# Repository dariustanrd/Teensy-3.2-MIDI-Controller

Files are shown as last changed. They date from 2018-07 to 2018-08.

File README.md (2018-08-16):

# Teensy 3.2 MIDI Controller / Macropad
A custom MIDI Controller / Macropad based on the [Teensy 3.2 microcontroller](https://www.pjrc.com/store/teensy32.html) for [MIDI2LR](https://github.com/rsjaffe/MIDI2LR/) integration and multi-keystroke macro execution.

Images of the final product can be seen either in this [gallery](https://imgur.com/a/6ZGOYGf) or at the end of this README.

## Inspiration for this project

Firstly, I was facing issues with editing a large number of images in Adobe Lightroom as it often takes a long time and it was not very intuitive to edit with my laptop's touchpad. Therefore, I stumbled upon MIDI2LR which uses MIDI Controllers normally used for music production to act as a physical device to change values in Lightroom.

Secondly, I wanted to create a macropad to perform tasks that would normally require multiple keypresses on the keyboard, such as while coding, CAD-ing etc., with a single press of a key.

Therefore, this controller serves 2 main purposes:
1. To send USB MIDI CC / NOTE messages in order to interface with MIDI2LR.
  
2. To send USB keyboard presses in order to chain multiple keypresses into a single macro key.

## Build Process
1. Mechanical & Electrical Fabrication
   
    I first purchased [this aluminium enclosure](https://item.taobao.com/item.htm?id=542717489532&_u=t2dmg8j26111) from Taobao, an online Chinese retailer, and milled out the holes for the encoders and the key switches to pass through. I designed a grid for the key switches in SolidWorks and fabricated it with a water jet machine out of 2mm Aluminium (which should have been 1.5mm Alu in hindsight). I then sand blasted the aluminium components and spray painted them black for aesthetic purposes.

   In order to cater for multiple functions on a single board, I added a SPDT Toggle Switch to connect to 2 digital pins on the Teensy to act as a Layer control mechanism to increase or decrease the current layer.

   As the Teensy has limited I/O slots and I wanted a large number of mechanical keyboard switches on my device to cater to the size of the enclosure I purchased, I wired up the Gateron Brown keyboard switches as well as the Encoder pushbuttons in a 4 x 7 matrix, with the help of the [Cherry MX breakout board](https://learn.sparkfun.com/tutorials/cherry-mx-switch-breakout-hookup-guide), similar to that of a regular keyboard matrix.

   Lastly, I wired all the components up to my Teensy 3.2, including 8 Incremental Rotary Encoders ([PEC11R-4215K-S0024](http://sg.element14.com/webapp/wcs/stores/servlet/ProductDisplay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)), 1 Potentiometer, 1 WS2812B LED strip, 1 SPDT toggle switch, my 4 x 7 switch matrix and 1 lonely Encoder pushbutton that could not fit on my switch matrix.

2. Code
   
   The first challenge that I tackled was interfacing with the Incremental Rotary Encoders. I used the [Teensy Encoder.h library](https://www.pjrc.com/teensy/td_libs_Encoder.html) for its ease of use and its interrupt capabilities since all digital pins on the Teensy 3.2 are interrupt capable.

   For the MIDI portion of the project, as my main purpose of using MIDI messages was to interface with MIDI2LR, I decided to send MIDI CC messages when I rotated my rotary encoders and MIDI NOTE messages when I pressed my mechanical key switches or encoder pushbuttons.

   Thus, when I rotated the encoders, which are mapped to specific CC numbers, the CC value would increment or decrement correspondingly on the MIDI channel that is defined by the current Layer that the device is in (controlled by the toggle switch).

   For the 4 x 7 keyswitch matrix, I setup a state machine in order to properly set the states of each individual switch be it IDLE, PRESSED, HOLD or RELEASED. Then, if the layer is currently on the lightroom layer, whether the switch is pressed or held, different MIDI NOTE messages will be sent. Otherwise, a keyboard macro will be sent instead. To send the keyboard press, the inbuilt [Teensy keyboard libary](https://www.pjrc.com/teensy/td_keyboard.html) is used. However, as there is no USB type for "Serial + MIDI + Keyboard", I edited the "Serial + MIDI" USB type in usb_desc.h to include keyboard functionality as well (inspiration from [here](https://forum.pjrc.com/threads/23942-Using-Serial-and-MIDI-USB-types-at-the-same-time).)

   Lastly, to be able to physically ascertain what layer the device is currently in, I changed the colour of the WS2812B LED strip using the [Teensy WS2812Serial.h library](https://github.com/PaulStoffregen/WS2812Serial) and added a cycling rainbow pattern for fun in the highest layer (which actually causes the teensy to be unable to perform other tasks, hence that layer is technically unusable but its just there for the sake of it).

## Images
Completed Device:
Top Profile

Side Profile of Device:
Side Profile

Milled Aluminium Enclosure:
Milled Alu Enclosure

Pre-assembly Layout:
Pre-assembly Layout

Internal Wiring:
Internal Wiring

Internal Wiring Closeup:
Internal Wiring Closeup

Front Profile:
Front Profile

Top Profile:
Top Profile

## GIFs
Top Profile GIF:

Top Profile GIF

Side Profile GIF:

Side Profile GIF

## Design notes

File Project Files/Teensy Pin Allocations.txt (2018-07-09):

Teensy 3.2 Pin Allocations

THROUGH HOLE
0 - ENC1A
1 - ENC1B
2 - ENC2A
3 - ENC2B
4 - ENC3A
5 - ENC3B
6 - ENC4A
7 - ENC4B
8 - ENC5A
9 - ENC5B
10 - ENC6A
11 - ENC6B
12 - ENC1PB
13 - RES/LED2 (Int LED)
14 - ENC7B
15 - ENC7A
16 - ENC8B
17 - ENC8A
18 - MATROW1
19 - MATROW2
20 - MATROW3
21 - MATROW4
22/A8 - TRIMPOT1
23/A9 - LINPOT1 ?

REAR PADS
24 - MATCOL7
25 - MATCOL6
26 - MATCOL5
27 - MATCOL4
28 - MATCOL3
29 - MATCOL2
30/A19 - SW_DWN
31/A20 - LED1
32/PWM - SW_UP
33 - MATCOL1

add switch

MATRIX
		MATCOL1	MATCOL2	MATCOL3	MATCOL4	MATCOL5	MATCOL6	MATCOL7

MATROW4		30		31		32		33		34		35		36
MATROW3		20		21		22		23		24		25		26
MATROW2		10		11		12		13		14		15		16
MATROW1		00		01		02		03		04		05		06

MIDI CC
ENC1 - 0
ENC2 - 1
ENC3 - 2
ENC4 - 3
ENC5 - 4
ENC6 - 5
ENC7 - 6
ENC8 - 7

ENC1PB - 8
ENC2PB - 9
ENC3PB - 10
ENC4PB - 11
ENC5PB - 12
ENC6PB - 13
ENC7PB - 14
ENC8PB - 15

K1->K21 - 16->36

1 enc detent = 5 cc val
24 enc det = 120 cc val

if 
1 enc det = 4 cc
24 enc det = 96 cc

Functions
-Hold button to increase sensitivity of encoders
	- done by using 1 detent = less num
use NOTE for keypads
change midi channel for layer

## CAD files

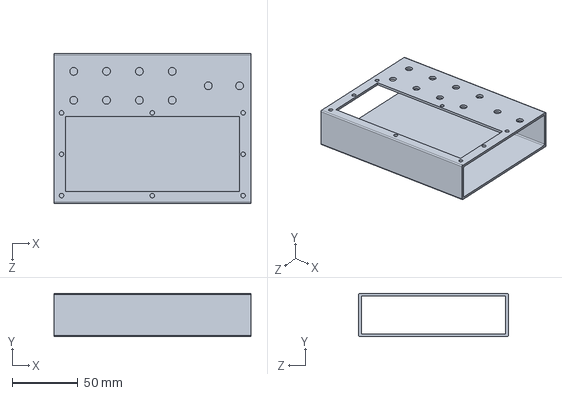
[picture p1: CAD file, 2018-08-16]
Project Files/CAD/Aluminium Enclosure.SLDPRT
150.0 x 33.1 x 114.0 mm

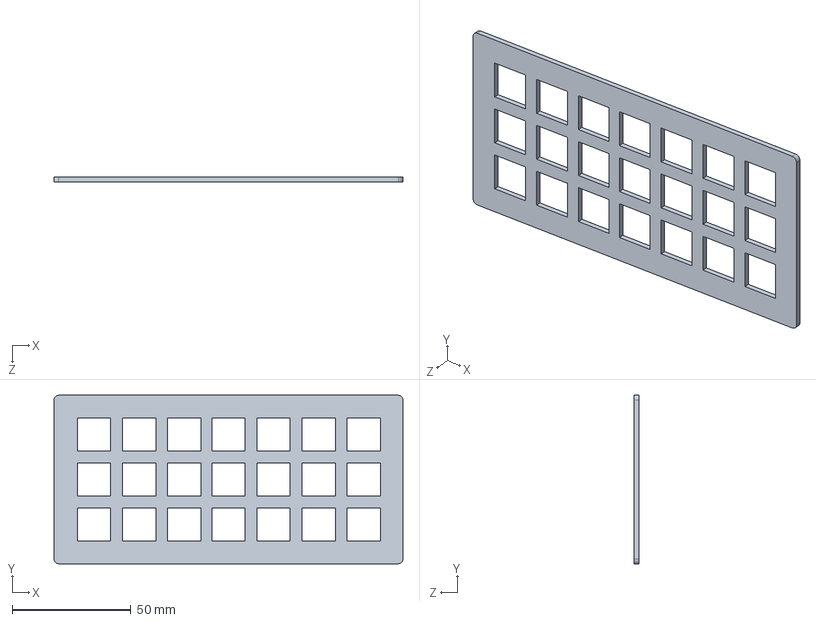
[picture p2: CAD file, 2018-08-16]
Project Files/CAD/Keycap Grid.SLDPRT
147.0 x 71.0 x 2.00 mm

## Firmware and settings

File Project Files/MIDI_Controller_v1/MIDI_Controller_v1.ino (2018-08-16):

//Code for Teensy 3.2 MIDI Controller / Macropad

#include <Encoder.h>
#include <WS2812Serial.h>

#define SW_UP 32
#define SW_DWN 30
#define LED1 31
#define ENC1PB 12
#define TRIMPOT 22

#define RESET 0
#define NUM_ENC 8
#define NUM_LEDS 8
#define MAX_LAYER 5

#define RED    0xFF0000
#define GREEN  0x00FF00
#define BLUE   0x0000FF
#define YELLOW 0xFFFF00
#define PINK   0xFF1088
#define ORANGE 0xE05800
#define WHITE  0xFFFFFF

//Declarations for Encoder Functionality*******************************************************************************************************************//
long enc_pos_new[NUM_ENC];
long enc_pos_old[NUM_ENC];
int enc_updateCCflag[NUM_ENC];

Encoder enc1(0, 1);
Encoder enc2(2, 3);
Encoder enc3(4, 5);
Encoder enc4(6, 7);
Encoder enc5(8, 9);
Encoder enc6(10, 11);
Encoder enc7(15, 14);
Encoder enc8(17, 16);

//Declarations for MIDI Functionality*******************************************************************************************************************//
byte midiChannel = 0;
byte enc_CC[NUM_ENC];
byte enc_CCVal[NUM_ENC];

volatile int sensitivity_val = 0;
bool SENS_KEY = true;

//Declarations for Keypad Functionality*******************************************************************************************************************//
byte rows[] = {18,19,20,21};
const int rowCount = sizeof(rows)/sizeof(rows[0]);

byte cols[] = {33,29,28,27,26,25,24};
const int colCount = sizeof(cols)/sizeof(cols[0]);

byte cur_encPB;
byte prev_encPB;
bool button_encPB;
bool stateChanged_encPB;
unsigned long encPB_holdTimer = 0;

byte curKeys[rowCount][colCount] = {};
byte prevKeys[rowCount][colCount] = {};
bool button[rowCount][colCount] = {};
bool stateChanged[rowCount][colCount] = {};
bool multiPress = false;

typedef enum{ IDLE, PRESSED, HOLD, RELEASED } KeyState;

unsigned long holdTimer = 0;
unsigned long holdTime = 1000; //hard code 1s

KeyState kstate[rowCount][colCount] = {};
KeyState state_encPB;

const int keymap[rowCount][colCount] = {
  {00,01,02,03,04,05,06},
  {10,11,12,13,14,15,16},
  {20,21,22,23,24,25,26},
  {30,31,32,33,34,35,36}
};

//Other Declarations*******************************************************************************************************************//
volatile int layer = 1;
bool curDWN = HIGH;
bool prevDWN = HIGH;
bool curUP = HIGH;
bool prevUP = HIGH;
int curTrim = 0;
int prevTrim = 0;
int smoothVal = 0;

byte drawingMemory[NUM_LEDS*3];         //  3 bytes per LED
DMAMEM byte displayMemory[NUM_LEDS*12]; // 12 bytes per LED

WS2812Serial leds(NUM_LEDS, displayMemory, drawingMemory, LED1, WS2812_GRB);

//Main Functions*******************************************************************************************************************//
void setup() {
  // Serial.begin(9600);
  SetupPin();
  SetupCC();
  SetupKeys();
  reset_enc();

  leds.begin();
}

void loop() {
  layerSelect();
  volumeSelect();
  switch(layer) {
      case 1:
        macropad();
        //Serial.print("Macropad Mode\n");
        setColour(BLUE);
      break;
      
      case 2:
        lightroom();
        setColour(PINK);
      break;

      case 3:
        //Premiere Pro Edit Layer?
        setColour(GREEN);
      break;

      case 4:
        //Coding Layer? 
        setColour(YELLOW);
      break;

      case 5:
        //end layer
        rainbowCycle(5);
      break;
      default:
        macropad();
    }
}

//Setup Functions*******************************************************************************************************************//
void SetupPin() {
  pinMode(SW_UP, INPUT_PULLUP);
  pinMode(SW_DWN, INPUT_PULLUP); 
  pinMode(ENC1PB, INPUT_PULLUP);
}
void SetupCC(){
  for (int i = 0; i < NUM_ENC; i++) {
    enc_CC[i] = i;
    enc_CCVal[i] = 64; //set CCVal to be middle upon init.
  }
}
void SetupKeys(){
  for(int x=0; x<colCount; x++) {
        // Serial.print(cols[x]); 
        // Serial.println(" as input");
        pinMode(cols[x], INPUT);
    }
 
    for (int x=0; x<rowCount; x++) {
        // Serial.print(rows[x]); 
        // Serial.println(" as input-pullup");
        pinMode(rows[x], INPUT_PULLUP);
    }

    for (int rowIndex=0; rowIndex < rowCount; rowIndex++) {
        for (int colIndex=0; colIndex < colCount; colIndex++) {
            kstate[rowIndex][colIndex] = IDLE;
        }
    }
    state_encPB = IDLE;
}
//Layer Function*******************************************************************************************************************//
void layerSelect() {
  //check if SW_up press, layer++. if SW_dwn press, layer--
  curUP = digitalRead(SW_UP);
  curDWN = digitalRead(SW_DWN);

  if (curUP == LOW && prevUP == HIGH) {
    if (layer != MAX_LAYER) {
      layer++;
    } else {
      layer = 1;
    }
    // Serial.println(layer);
  } 
  prevUP = curUP;
  
  if (curDWN == LOW && prevDWN == HIGH) {
    if (layer != 1) {
      layer--;
    } else {
      layer = MAX_LAYER;
    }
    // Serial.println(layer);
  }
  prevDWN = curDWN;

  midiChannel = layer;
}
//Volume (TRIMPOT) Function*******************************************************************************************************************//
void volumeSelect() {
  int trimVal = analogRead(TRIMPOT);
  float smoothing = 0.2; //lower more stable
  
  smoothVal = (smoothing*trimVal) + ((1-smoothing)*smoothVal);
  
  curTrim = map(smoothVal, 0, 1023, 0, 100);
  
  if (curTrim != prevTrim) {
    // Serial.println(curTrim);
    if (curTrim <= 5 ) {
    // Serial.println("Mute");
      Keyboard.press(KEY_MEDIA_MUTE);
      Keyboard.release(KEY_MEDIA_MUTE);
    } 
    else {
      if (curTrim > prevTrim) {
        // Serial.println("Increasing");
        Keyboard.press(KEY_MEDIA_VOLUME_INC);
        Keyboard.release(KEY_MEDIA_VOLUME_INC);
      } 
      else if (curTrim < prevTrim) {
        // Serial.println("Decreasing");
        Keyboard.press(KEY_MEDIA_VOLUME_DEC);
        Keyboard.release(KEY_MEDIA_VOLUME_DEC);
      }
    }
    prevTrim = curTrim;
  }
}

//LED Functions*******************************************************************************************************************//
void setColour (int colour) {
  for (int i=0; i < leds.numPixels(); i++) {
    leds.setPixel(i, colour);
    leds.show();
  }
}

void rainbowCycle(int SpeedDelay) {
  byte *c;
  uint16_t i, j;

  for(j=0; j<256*5; j++) { // 5 cycles of all colors on wheel
    for(i=0; i< NUM_LEDS; i++) {
      c=Wheel(((i * 256 / NUM_LEDS) + j) & 255);
      leds.setPixel(i, *c, *(c+1), *(c+2));
    }
    leds.show();
    delay(SpeedDelay);
  }
}

byte * Wheel(byte WheelPos) {
  static byte c[3];
  
  if(WheelPos < 85) {
   c[0]=WheelPos * 3;
   c[1]=255 - WheelPos * 3;
   c[2]=0;
  } else if(WheelPos < 170) {
   WheelPos -= 85;
   c[0]=255 - WheelPos * 3;
   c[1]=0;
   c[2]=WheelPos * 3;
  } else {
   WheelPos -= 170;
   c[0]=0;
   c[1]=WheelPos * 3;
   c[2]=255 - WheelPos * 3;
  }
  return c;
}
//Encoder Functions*******************************************************************************************************************//
void reset_enc(){
  enc1.write(RESET);
  enc2.write(RESET);
  enc3.write(RESET);
  enc4.write(RESET);
  enc5.write(RESET);
  enc6.write(RESET);
  enc7.write(RESET);
  enc8.write(RESET);
  // Serial.print("ENC Reset\n");
}

void read_enc() {
  enc_pos_new[0] = enc1.read();
  enc_pos_new[1] = enc2.read();
  enc_pos_new[2] = enc3.read();
  enc_pos_new[3] = enc4.read();
  enc_pos_new[4] = enc5.read();
  enc_pos_new[5] = enc6.read();
  enc_pos_new[6] = enc7.read();
  enc_pos_new[7] = enc8.read();

  //check if old and new positions of each encoder need to change CC val
  for (int i = 0; i < NUM_ENC; i++) {
    enc_updateCCflag[i] = check_pos(enc_pos_new[i], enc_pos_old[i]);
    enc_pos_old[i] = enc_pos_new[i];
    enc_CCVal[i] = update_CCVal(enc_updateCCflag[i], enc_CCVal[i]);
  }
}
int check_pos(long encPos_new, long encPos_old) {
  if (encPos_new == encPos_old) {
    return 0;
  }
  if(encPos_new %4 != 0) { 
    return 0;
  }
  if (encPos_new > encPos_old) {
    return 1; //positive direction, flag increase
  } else {
    return -1; //negative direction, flag decrease
  }
}
byte update_CCVal(long flag, byte CCVal) {
  SENS_KEY = true; //HARDCODE, CHANGE WHEN GOT KEYPAD
  check_sens();

  if (sensitivity_val == 1){
    if (flag == 1) {
      if (CCVal != 127) {
        CCVal += sensitivity_val;
      } else {
        CCVal = 0;
      }
    }
    else if (flag == -1) {
      if (CCVal != 0) {
        CCVal -= sensitivity_val;
      } else {
        CCVal = 127;
      }
    }
  } else {
    if (flag == 1) {
      if (CCVal <= 127) {
        CCVal += sensitivity_val;
      } else {
        CCVal = 0;
      }
    }
    else if (flag == -1) {
      if ((CCVal <= 127 )) {
        CCVal -= sensitivity_val;
      } else {
        CCVal = 127;
      }
    }
  }

  return CCVal;
}

void send_enc_CC() {
  //send CC values for all enc if they have an update
  for (int i = 0; i < NUM_ENC; i++) {
    if (enc_updateCCflag[i]!=0) {
      usbMIDI.sendControlChange(enc_CC[i], enc_CCVal[i], midiChannel);
      // Serial.print("CC Change = ");
      // Serial.print(enc_CCVal[i]);
      // Serial.println();
    }
  }
}

void check_sens(){
  if (SENS_KEY) {
    sensitivity_val = 1;
  } else {
    sensitivity_val = 5;
  }
}
//Keypad Functions*******************************************************************************************************************//
void read_keys() {
    //read single encPB ENC1PB not on matrix
    cur_encPB = digitalRead(ENC1PB);
    if (cur_encPB == 0 && prev_encPB == 1) {
      button_encPB = 0;
      prev_encPB = cur_encPB;
    }
    if (cur_encPB == 1 && prev_encPB == 0) {
      button_encPB = 1;
      prev_encPB = cur_encPB;
    }
    encPB_stateMachine();

    // iterate the rows
    for (int rowIndex=0; rowIndex < rowCount; rowIndex++) {
        // row: set to output to low
        byte curRow = rows[rowIndex];
        pinMode(curRow, OUTPUT);
        digitalWrite(curRow, LOW);
        
        // col: interate through the cols
        for (int colIndex=0; colIndex < colCount; colIndex++) {
            byte rowCol = cols[colIndex];
            pinMode(rowCol, INPUT_PULLUP);
            delayMicroseconds(10); //to prevent overlap of readings
            curKeys[rowIndex][colIndex] = digitalRead(rowCol);
            
            
            //curKeys tracks the current status of the key. 1 == released, 0 == pressed
            //following 2 if statements ensure only single button press and release
            if (curKeys[rowIndex][colIndex] == 0 && prevKeys[rowIndex][colIndex] == 1) {
                button[rowIndex][colIndex] = 0;
                prevKeys[rowIndex][colIndex] = curKeys[rowIndex][colIndex];
            }
            if (curKeys[rowIndex][colIndex] == 1 && prevKeys[rowIndex][colIndex] == 0) {
                button[rowIndex][colIndex] = 1;
                prevKeys[rowIndex][colIndex] = curKeys[rowIndex][colIndex];
            }

            //function for key state changes -- state machine
            kstateMachine(rowIndex,colIndex);
            pinMode(rowCol, INPUT);
        }
        // disable the column
        pinMode(curRow, INPUT);
    }
}
void encPB_stateMachine() {
  stateChanged_encPB = false;
  switch (state_encPB) {
    case IDLE:
      if (button_encPB == 0) {
        state_encPB = PRESSED;
        stateChanged_encPB = true;
        encPB_holdTimer = millis();
      }
    break;
    case PRESSED:
      if ((millis()-encPB_holdTimer)>holdTime) {
        state_encPB = HOLD;
        stateChanged_encPB = true;
      } else if (button_encPB == 1) {
        state_encPB = RELEASED;
        stateChanged_encPB = true;
      }
    break;
    case HOLD:
      if (button_encPB == 1) {
        state_encPB = RELEASED;
        stateChanged_encPB = true;
      }
    break;
    case RELEASED:
      state_encPB = IDLE;
      stateChanged_encPB = true;
    break;
  }
}

void kstateMachine(int row, int col){
  stateChanged[row][col] = false;
  switch (kstate[row][col]) {
    case IDLE:
      if (button[row][col] == 0){
        kstate[row][col] = PRESSED;
        stateChanged[row][col] = true;
        holdTimer = millis();
      }
      break;
    case PRESSED:
      if ((millis()-holdTimer)>holdTime) {
        kstate[row][col] = HOLD;
        stateChanged[row][col] = true;
      } else if (button[row][col] == 1) {
        kstate[row][col] = RELEASED;
        stateChanged[row][col] = true;
      }
      break;
    case HOLD:
      if (button[row][col] == 1) {
        kstate[row][col] = RELEASED;
        stateChanged[row][col] = true;
      }
      break;
    case RELEASED:
      kstate[row][col] = IDLE;
      stateChanged[row][col] = true;
      break;
  }
}

void send_keys() {
  //for single enc key
  if(stateChanged_encPB == true) {
    switch (state_encPB) {
      case IDLE:
        // Serial.print("encPB");
        // Serial.println(" IDLE");
      break;

      case PRESSED:
        // Serial.print("encPB");
        // Serial.println(" PRESSED");
        keyPress_func(99); //hardcode value for the encPB
      break;

      case HOLD:
        // Serial.print("encPB");
        // Serial.println(" HOLD");
        keyHold_func(99); //hardcode value for the encPB
      break;

      case RELEASED:
        // Serial.print("encPB");
        // Serial.println(" RELEASED");
      break;
    }
  }
  //for single key presses in matrix
  for (int rowIndex=0; rowIndex < rowCount; rowIndex++) {
    for (int colIndex=0; colIndex < colCount; colIndex++) {
      if (stateChanged[rowIndex][colIndex] == true){
        switch (kstate[rowIndex][colIndex]){
          case IDLE:
            // Serial.print(keymap[rowIndex][colIndex]);
            // Serial.println(" IDLE");
          break;

          case PRESSED:
            // Serial.print(keymap[rowIndex][colIndex]);
            // Serial.println(" PRESSED");
            keyPress_func(keymap[rowIndex][colIndex]);
          break;

          case HOLD:
            // Serial.print(keymap[rowIndex][colIndex]);
            // Serial.println(" HOLD");
            keyHold_func(keymap[rowIndex][colIndex]);
          break;

          case RELEASED:
            // Serial.print(keymap[rowIndex][colIndex]);
            // Serial.println(" RELEASED");
          break;
        }
      }
    }
  }
  //for multi of 4 corner keys
  //this code is kinda spaghetti-ish as operands such as || and && are not supposed to be used in this manner for an enum. but it works here.
  if ((stateChanged[0][0] || stateChanged[0][6] || stateChanged[2][0] || stateChanged[2][6]) == true) {
    if (((kstate[0][0] && kstate[0][6] && kstate[2][0] && kstate[2][6]) == PRESSED) 
    && (multiPress == false)) {
      // Serial.println("multi PRESS");
      //is there any way to reset the serial? mimic a power cycle?
      Keyboard.press(KEY_SYSTEM_SLEEP);
      Keyboard.release(KEY_SYSTEM_SLEEP);
      multiPress = true;
    }
    if (((kstate[0][0] == RELEASED) || (kstate[0][6] == RELEASED) ||
    (kstate[2][0] == RELEASED) || (kstate[2][6] == RELEASED)) && (multiPress == true)) {
      // Serial.println("multi RELEASE");
      multiPress = false;
    }
  }
}

void keyPress_func(int key) {
  if (layer == 1) { //for macropad see https://www.pjrc.com/teensy/td_keyboard.html
    switch (key) {
      case 0:
        Keyboard.press(KEY_MEDIA_VOLUME_DEC);
        Keyboard.release(KEY_MEDIA_VOLUME_DEC);
      break;
      case 1:
        Keyboard.press(KEY_MEDIA_PREV_TRACK);
        Keyboard.release(KEY_MEDIA_PREV_TRACK);        
      break;
      case 2: //open command palette
        Keyboard.set_modifier(MODIFIERKEY_CTRL | MODIFIERKEY_SHIFT);
        Keyboard.send_now();
        Keyboard.press(KEY_P);
        Keyboard.release(KEY_P);
        Keyboard.set_modifier(0);
        Keyboard.send_now();
      break;
      case 3:
        //code
      break;
      case 4:
        //winkey ctrl left see virtual desktop right
        Keyboard.set_modifier(MODIFIERKEY_GUI | MODIFIERKEY_CTRL);
        Keyboard.send_now();
        Keyboard.press(KEY_LEFT);
        Keyboard.release(KEY_LEFT);
        Keyboard.set_modifier(0);
        Keyboard.send_now();
      break;
      case 5:
        //winkey tab see task view
        Keyboard.set_modifier(MODIFIERKEY_GUI);
        Keyboard.send_now();
        Keyboard.press(KEY_TAB);
        Keyboard.release(KEY_TAB);
        Keyboard.set_modifier(0);
        Keyboard.send_now();
      break;
      case 6:
        //winkey ctrl right see virtual desktop right
        Keyboard.set_modifier(MODIFIERKEY_GUI | MODIFIERKEY_CTRL);
        Keyboard.send_now();
        Keyboard.press(KEY_RIGHT);
        Keyboard.release(KEY_RIGHT);
        Keyboard.set_modifier(0);
        Keyboard.send_now();
      break;
      case 10:
        Keyboard.press(KEY_MEDIA_MUTE);
        Keyboard.release(KEY_MEDIA_MUTE);
      break;
      case 11:
        Keyboard.press(KEY_MEDIA_PLAY_PAUSE);
        Keyboard.release(KEY_MEDIA_PLAY_PAUSE);
      break;
      case 12:
        //code
      break;
      case 13:
        //code
      break;
      case 14:
        //code
      break;
      case 15:
        //code
      break;
      case 16:
        //code
      break;
      case 20:
        Keyboard.press(KEY_MEDIA_VOLUME_INC);
        Keyboard.release(KEY_MEDIA_VOLUME_INC);
      break;
      case 21:
        Keyboard.press(KEY_MEDIA_NEXT_TRACK);
        Keyboard.release(KEY_MEDIA_NEXT_TRACK);
      break;
      case 22:
        //code
      break;
      case 23:
        //code
      break;
      case 24:
        //code
      break;
      case 25:
        //code
      break;
      case 26:
        //code
      break;
      case 30:
        //code
      break;
      case 31:
        //code
      break;
      case 32:
        //code
      break;
      case 33:
        //code
      break;
      case 34:
        //code
      break;
      case 35:
        //code
      break;
      case 36:
        //code
      break;
      case 99: //encPB case
        //code
      break;
    }
  } else if (layer == 2) { //for lightroom layer
    usbMIDI.sendNoteOn(key, 99, midiChannel);
    usbMIDI.sendNoteOff(key, 0, midiChannel);
    switch (key) { //to reset enc values for MIDI2LR
      case 3: //to coincide with MIDI2LR left and right keys resetting encoder values
        for (int i = 0; i < NUM_ENC; i++) {
          enc_CCVal[i] = 64;
        }
      break;
      case 5: //to coincide with MIDI2LR left and right keys resetting encoder values
        for (int i = 0; i < NUM_ENC; i++) {
          enc_CCVal[i] = 64;
        }
      break;
      case 6: //to coincide with MIDI2LR profile 3 key resetting encoder values
        for (int i = 0; i < NUM_ENC; i++) {
          enc_CCVal[i] = 64;
        }
      break;
      case 16: //to coincide with MIDI2LR left and right keys resetting encoder values
        for (int i = 0; i < NUM_ENC; i++) {
          enc_CCVal[i] = 64;
        }
      break;
      case 26: //to coincide with MIDI2LR left and right keys resetting encoder values
        for (int i = 0; i < NUM_ENC; i++) {
          enc_CCVal[i] = 64;
        }
      break;
      case 30:
        enc_CCVal[6] = 64;
      break;
      case 31:
        enc_CCVal[7] = 64;
      break;
      case 32:
        enc_CCVal[5] = 64;
      break;
      case 33:
        enc_CCVal[4] = 64;
      break;
      case 34:
        enc_CCVal[3] = 64;
      break;
      case 35:
        enc_CCVal[2] = 64;
      break;
      case 36:
        enc_CCVal[1] = 64;
      break;
      case 99: //encPB case
        enc_CCVal[0] = 64;
      break;
    }
  }
}

void keyHold_func(int key) {
  if (layer == 1) { //for macropad
    switch (key) {
      case 0:
        //code
      break;
      case 1:
        //code
      break;
      case 2:
        //code
      break;
      case 3:
        //code
      break;
      case 4:
        //code
      break;
      case 5:
        //code
      break;
      case 6:
        //code
      break;
      case 10:
        //code
      break;
      case 11:
        //code
      break;
      case 12:
        //code
      break;
      case 13:
        //code
      break;
      case 14:
        //code
      break;
      case 15:
        //code
      break;
      case 16:
        //code
      break;
      case 20:
        //code
      break;
      case 21:
        //code
      break;
      case 22:
        //code
      break;
      case 23:
        //code
      break;
      case 24:
        //code
      break;
      case 25:
        //code
      break;
      case 26:
        //code
      break;
      case 30:
        //code
      break;
      case 31:
        //code
      break;
      case 32:
        //code
      break;
      case 33:
        //code
      break;
      case 34:
        //code
      break;
      case 35:
        //code
      break;
      case 36:
        //code
      break;
      case 99: //encPB case
        //code
      break;
    }
  }  else if (layer == 2) { //for lightroom layer
    int holdKey = key + 28; //to push to new set of keys, non overlapping single press key value
    usbMIDI.sendNoteOn(holdKey, 99, midiChannel);
    usbMIDI.sendNoteOff(holdKey, 0, midiChannel);
  }
}
//Layer Functions*******************************************************************************************************************//
void macropad() {
//  read_enc();
//  send_enc_CC();
  read_keys();
  send_keys();
  
  //change LED
}

void lightroom() {
  read_enc();
  send_enc_CC();
  read_keys();
  send_keys();
}

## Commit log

2018-07-09 Edited Teensy usb_desc for MIDI + Serial to have Keyboard as well.
2018-07-09 Added LED Strip
2018-07-11 hardcode reset enc values for midi2lr
    [MIDI_Controller_v1.ino]
2018-08-16 Added CAD
    [Aluminium Enclosure.SLDPRT, Keycap Grid.SLDPRT]
